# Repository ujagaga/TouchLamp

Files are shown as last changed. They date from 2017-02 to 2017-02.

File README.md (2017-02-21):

# TouchLamp

This is the PCB and Firmware for an LED lamp acivated by a touch on the sensor. 

The firmware is written using Eclipse and AVR toolchain. I used AtTiny2313, but you can use any Atmel MCU with at least 1KB of flash.

The sensor can be a piece of metal (preferably isolated with paint) size of a couple of sqare centimeters. The size is not critical. 
I have used a piece of copper 1x1cm and also 3x3cm. The firmware automatically calibrates at startup.

When you hold your finger on the sensor, the light intensity increases. If you touch it shortly, the light toggles on/off.
The preset light intensity is saved in the EEPROM so it does not get forgotten through power failures.

The touch is detected through changes in the capacity by measuring the time it takes to charge the capacitor, so you should not use long wires to connect the sensor.
Using a coaxial cable would increase minimum capacity and decrease change in capacity. Sensitivity can be adjusted by changing the "DETECT_COEF".
The length of the sensor wire should not exceed 10cm. There is also a fixed capacity which is used as a reference because the threashold of logic levels changes
as the controller operates.

I used F_CPU 8MHz, but it should work with any other frequency. If you use smaller frequency, you get less resolution and less sensitivity.
I used prototype PCB with dots at 2,54mm and did my best to minimize the PCB size. The transistor is in SMD package, but you could use any other transistor in any other package.

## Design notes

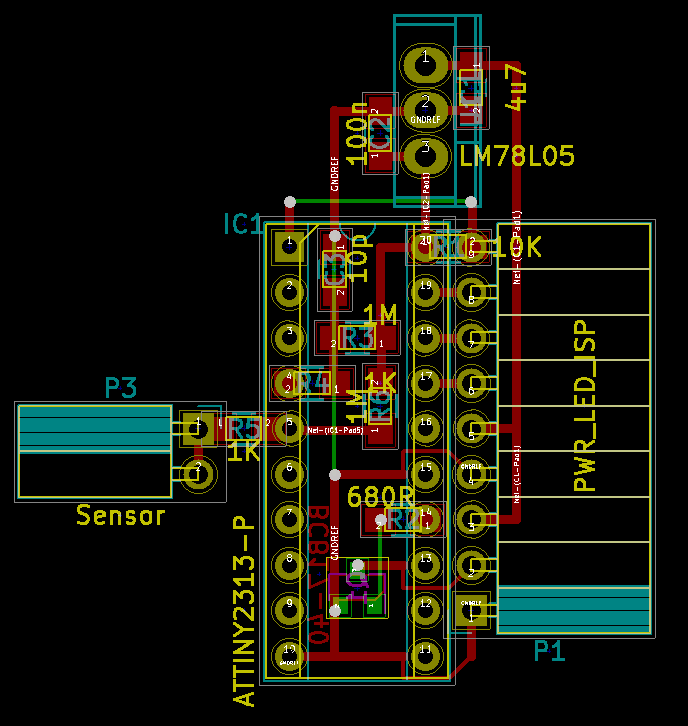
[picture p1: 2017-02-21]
PCB/PCB_layout.png

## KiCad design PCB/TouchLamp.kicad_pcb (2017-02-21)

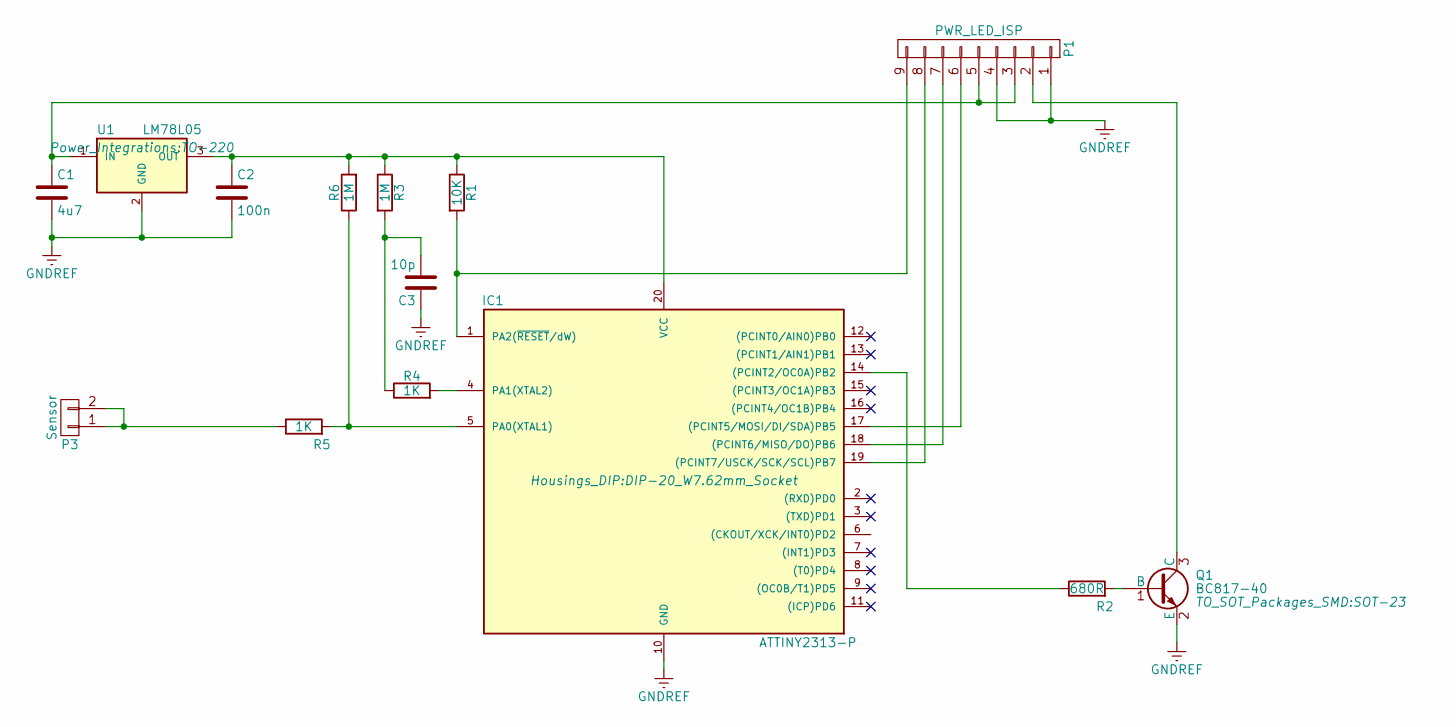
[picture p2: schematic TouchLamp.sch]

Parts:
C1: 4u7; C_0805_HandSoldering
C2: 100n; C_0805_HandSoldering
C3: 10p; C_0805_HandSoldering
IC1: ATTINY2313-P; DIP-20_W7.62mm_Socket
P1: PWR_LED_ISP; Socket_Strip_Angled_1x09_Pitch2.54mm
P3: Sensor; Socket_Strip_Angled_1x02_Pitch2.54mm
Q1: BC817-40; SOT-23
R1: 10K; R_0805_HandSoldering
R2: 680R; R_0805_HandSoldering
R3, R6: 1M; R_0805_HandSoldering
R4, R5: 1K; R_0805_HandSoldering
U1: LM78L05; TO-220

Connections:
GNDREF: C1.2, C2.2, C3.1, IC1.10 (GND), P1.1, P1.4, Q1.2 (E), U1.2 (GND)
unnamed: C1.1, P1.3, P1.5, U1.1 (IN)
unnamed: C2.1, IC1.20 (VCC), R1.1, R3.1, R6.2, U1.3 (OUT)
unnamed: C3.2, R3.2, R4.1
unnamed: IC1.1 (PA2(~RESET~/dW)), P1.9, R1.2
unnamed: IC1.4 (PA1(XTAL2)), R4.2
unnamed: IC1.5 (PA0(XTAL1)), R5.2, R6.1
unnamed: IC1.14 ((PCINT2/OC0A)PB2), R2.1
unnamed: IC1.17 ((PCINT5/MOSI/DI/SDA)PB5), P1.6
unnamed: IC1.18 ((PCINT6/MISO/DO)PB6), P1.7
unnamed: IC1.19 ((PCINT7/USCK/SCK/SCL)PB7), P1.8
unnamed: P1.2, Q1.3 (C)
unnamed: P3.1, P3.2, R5.1
unnamed: Q1.1 (B), R2.2

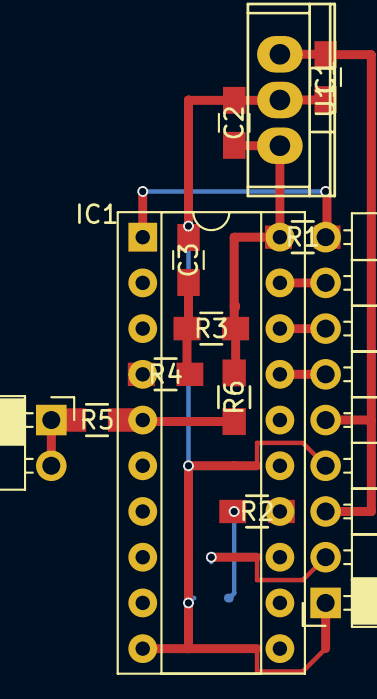
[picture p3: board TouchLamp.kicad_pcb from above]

Board: 2 copper layers, 14 parts (1 on the bottom side), 14 nets.

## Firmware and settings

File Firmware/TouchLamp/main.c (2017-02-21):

/*
 * main.c
 *
 *  Created on: Feb 15, 2016
 *      Author: ujagaga
 */


#include <avr/io.h>
#include <util/delay.h>
#include <stdint.h>
#include <stdbool.h>
#include <avr/eeprom.h>


/* Working configuration.
 * The assumption is that we are using the same port for the sensor and ethalon pin.
 * The LED pin must be PB2 since it is connected to Timer0 OCM */
#define ETALON_MASK				(1 << PA1)	// Pin to measure the fixed capacity charge time as it may change in time or with voltage
#define SENS_MASK				(1 << PA0) 	// Pin where the sensor is connected
#define PORT					PORTA		// Control port output register
#define PIN						PINA		// Control port input register
#define DIR						DDRA		// Control port direction register
#define DETECT_COEF				25			/* Minimum percentage expected for sensor capacity to change when touched. The lower it is,
											   the more sensitive the sensor is, but also less	noise resistant */
/* End of working cfg */


/* Global variables */
uint8_t pwm_count = 0;
uint8_t EEMEM savedPwm;
uint16_t ratio;		/* ratio between charge time of fixed capacitor and sensor	*/

/* PWM control macros */
#define PwmOff()				do{ OCR0A = 0;}while(0)
#define PwmOn()					do{ OCR0A = pwm_count;}while(0)
#define PwmUp()					do{	OCR0A <<= 1; OCR0A++; pwm_count = OCR0A;} while(0)
#define isPwmOn()				(OCR0A > 0)

#define PwmTgl()				if(OCR0A == 0){		\
									PwmOn();		\
								}else{				\
									PwmOff();		\
								}

/* Detect macros */
#define SensEtalon()			((PIN & ETALON_MASK) == ETALON_MASK)
#define SensDetect()			((PIN & SENS_MASK) == SENS_MASK)

/* Helper debug macro */
#define ledDbg()				do{OCR0A = 64; _delay_ms(200); OCR0A = 0;}while(0)


void HwInit( void )
{

	DIR = ETALON_MASK | SENS_MASK;
	PORT = ~(ETALON_MASK | SENS_MASK);		// Activate pull-up resistors on free pins to prevent self oscillation

	DDRB |= (1 << PB2);						// LED pin as output
	PORTB |= ~(1 << PB2);					// LED off

	TCCR1B = (1<<CS10);						// Start timer 1 with no pre-scaler

	/* Timer 0 */
	TCCR0A = (1 << COM0A1) | (1 << WGM00);  // phase correct PWM mode
	OCR0A  = 0;                          	// initial PWM pulse width
	TCCR0B = (1 << CS01);   				// clock source = CLK/8, start PWM

	pwm_count = eeprom_read_byte(&savedPwm);
}

void clearSensor( void ){
	DIR |= ETALON_MASK | SENS_MASK;		// set sensor pins to output
	PORT &= ~(ETALON_MASK | SENS_MASK);	// clear sensor pins
	_delay_ms(10);
	DIR &= ~(ETALON_MASK | SENS_MASK);	// set sensor pins to input
}


/* Function to detect a touch on the sensor.
 * It measures the fixed capacity on "ETHALON" pin and compares it to capacity on "SENSOR" pin.This algorithm
 * assumes that both the ETHALON capacitor charge time and SENSOR charge time are less then 256 units of timer 1.
 * */
bool touchDetected( void )
{
	uint16_t etalon_time, detect_time, threashold;

	clearSensor();

	TCNT1 = 0;
	while(!SensEtalon());

	etalon_time = TCNT1;

	clearSensor();

	TCNT1 = 0;
	while(!SensDetect());
	detect_time = TCNT1;

	threashold = (((etalon_time * 10) / ratio) * (100 + DETECT_COEF)) / 100;

	if(detect_time > threashold){
		return true;
	}

	return false;

}

/* Implements a low pass filter in case of noise
 * */
bool isTouched( void )
{
	uint8_t touchCount = 0;
	uint8_t touchAttempt;

	for(touchAttempt = 0; touchAttempt < 10; touchAttempt++){
		if(touchDetected()){
			touchCount++;
		}
	}

	if(touchCount > 2){
		return true;
	}

	return false;

}


/* Calculates the ratio between the "ETHALON" capacity and "SENSOR" capacity
 * because the charge time may vary with different setup*/
void calibrate( void )
{
	uint16_t etalon_time, detect_time;

	clearSensor();

	TCNT1 = 0;
	while(!SensEtalon());
	etalon_time = TCNT1;

	clearSensor();

	TCNT1 = 0;
	while(!SensDetect());
	detect_time = TCNT1;

	ratio = (etalon_time * 10) / detect_time;

}

int main(void)
{
	uint8_t touchCount;

	HwInit();

	calibrate();

	while(1){
		touchCount = 0;

		if(isTouched()){

			while(isTouched()){
				touchCount++;

				if((touchCount % 2) == 0){
					PwmUp();
				}
			}

			if(touchCount < 2){
				/* Only one short touch */
				PwmTgl();
			}else{
				eeprom_update_byte(&savedPwm, pwm_count);
			}
		}
	}

	return 0;
}

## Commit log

2017-02-21 PCB, Schematic and FW
    [TouchLamp.kicad_pcb, TouchLamp.sch]
2017-02-21 optimized the PCB and adjusted the FW
    [TouchLamp.kicad_pcb, TouchLamp.sch]
2017-02-21 Added low pass filter to sensor detection routine
